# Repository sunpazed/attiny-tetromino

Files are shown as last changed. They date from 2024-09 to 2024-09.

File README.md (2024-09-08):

# attiny-tetromino 



This is my second-ever PCB, an Arduino Tetris game based around a attiny85. Most of the code was inspired by this hack https://github.com/jfoucher/attiny-tetris/ — however I made a number of modern modifications to Tetris (7-bag randomiser, DAS, debounce, NES speed improvements, new level and line system, new fonts). 

I started with a breadboard and then thought I'd try my hand at designing a PCB in Kicad. Here's [version 1](https://www.reddit.com/r/arduino/comments/1eph7te/my_first_pcb_an_arduino_attiny85_handheld/) and this project is version 2. Please excuse my poor hand soldering, as I'm only just beginning!

The game is quite small, at 50x44mm it's easily pocketable. The side profile is only 14mm, and could be make thinner by using a smaller battery holder.



## How to build your own

### Part list

The parts are relatively inexpensive, with the entire BOM and board costing less than $10 in total. To accomodate easier soldering I've selected larger surface mount components where possible, and the pads on the board are also wider.

- 1x attiny85-20su
- 1x SDD1306 monochrome OLED (128x32 pixels)
- 1x Mini 7-pin SMD toggle slide switch, [SPDT MSK-12C02](https://www.ckswitches.com/media/1424/pcm.pdf) 
- 4x SMD micro-switch 6x6x5mm
- 1x 470k SMD resistor (2512 size)
- 1x battery holder CR2032, [Keystone 1060](https://www.ckswitches.com/media/1424/pcm.pdf)

### Make the PCB

Order a PCB using the gerber files within the `pcb/fabrication` folder — simply zip this up and process the files through your favourite prototyping fab. The source also includes the Kicad project if you'd like to modify the PCB, components, or even just the silkscreen graphics.

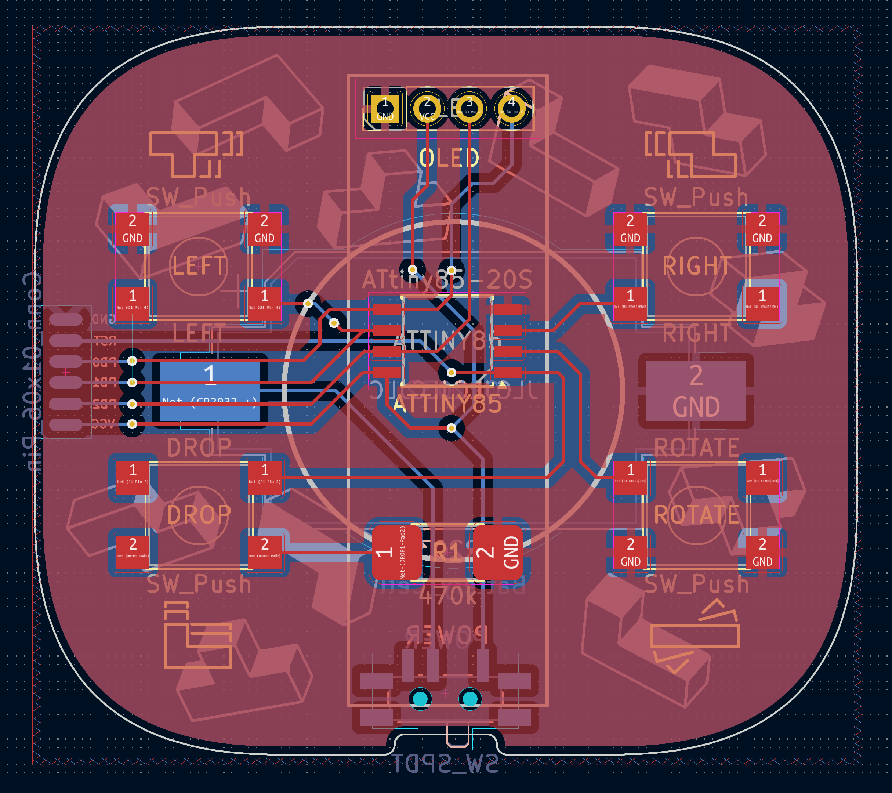
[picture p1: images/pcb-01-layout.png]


### Programming the board

The board includes 6 programming pads directly connected to the attiny. You can see them here on the right-hand side of the rear of the pcb; 

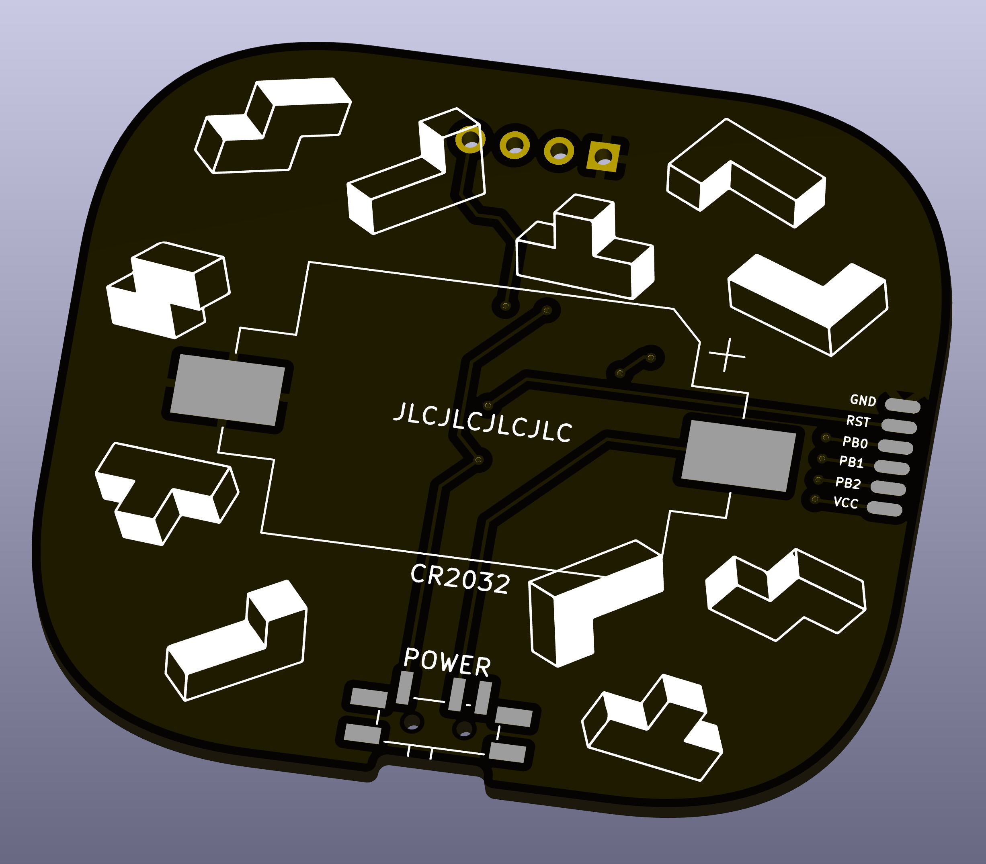
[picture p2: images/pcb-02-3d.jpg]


These can be easily connected using a SOP16 programming clip for SOIC16 chips. Only the top section of the clip is used, and is mapped to GND, RST, PB0, PB1, PB3, and VCC. Connect the programming clip to your programming device or Arduino using DuPont jumper wires — learn more at [SOICBite](https://github.com/SimonMerrett/SOICbite)

Once the board is connected, load up the Arduino IDE and test the connection by burning the bootloader to the attiny. The bootloader configuration is defined within the `attiny_tetromino.ino` project.

If the bootloader completes without issue, you can now compile and upload the `attiny_tetromino.ino` project to your board. Pop in a CR2032 battery and enjoy playing!

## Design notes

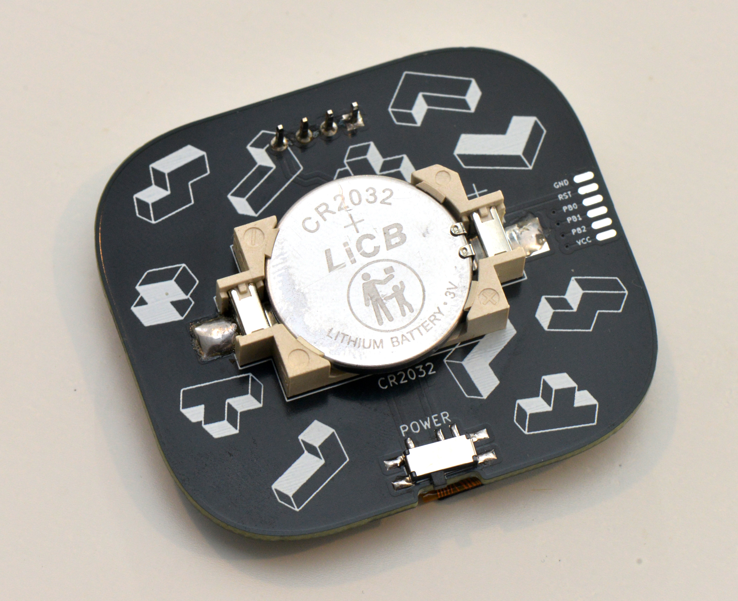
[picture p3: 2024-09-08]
images/device-rear.jpg

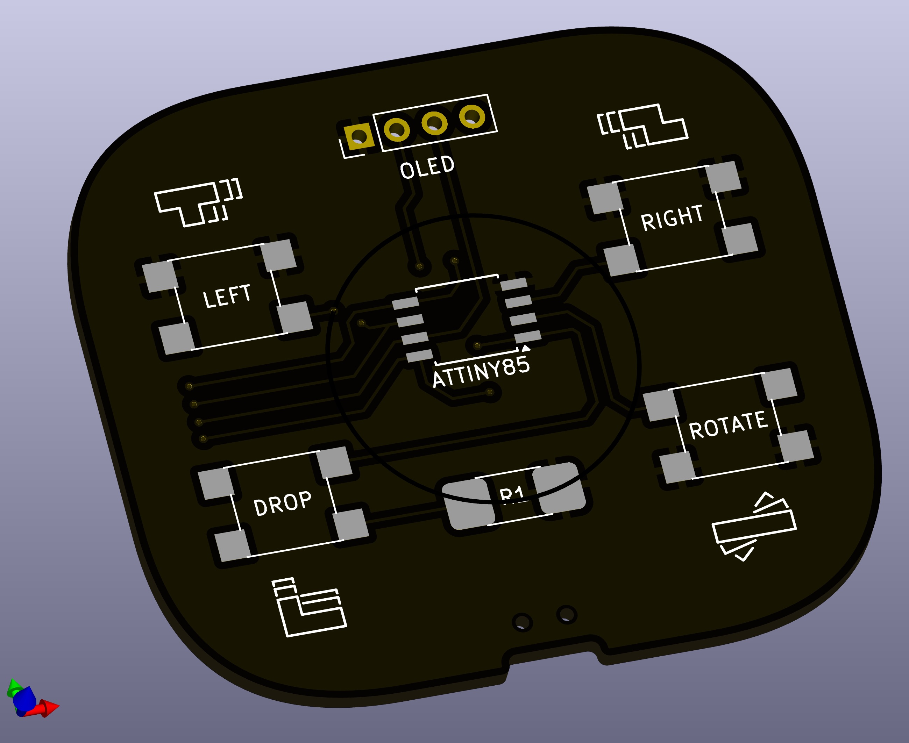
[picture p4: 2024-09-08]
images/pcb-03-3d.jpg

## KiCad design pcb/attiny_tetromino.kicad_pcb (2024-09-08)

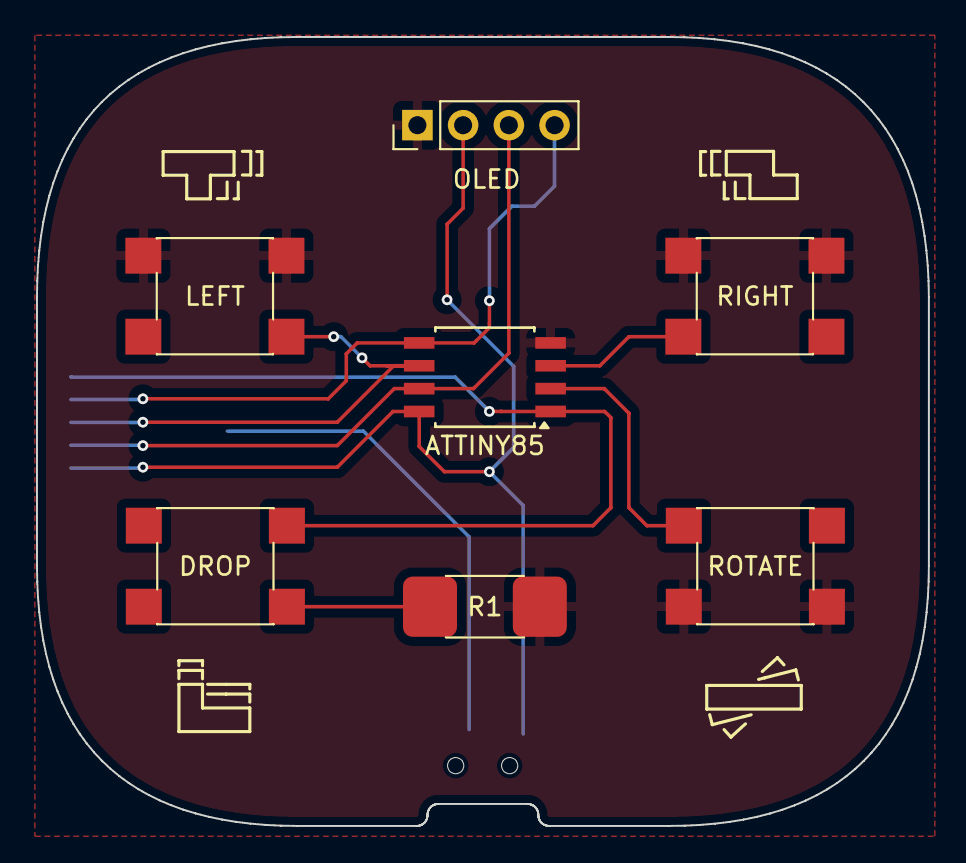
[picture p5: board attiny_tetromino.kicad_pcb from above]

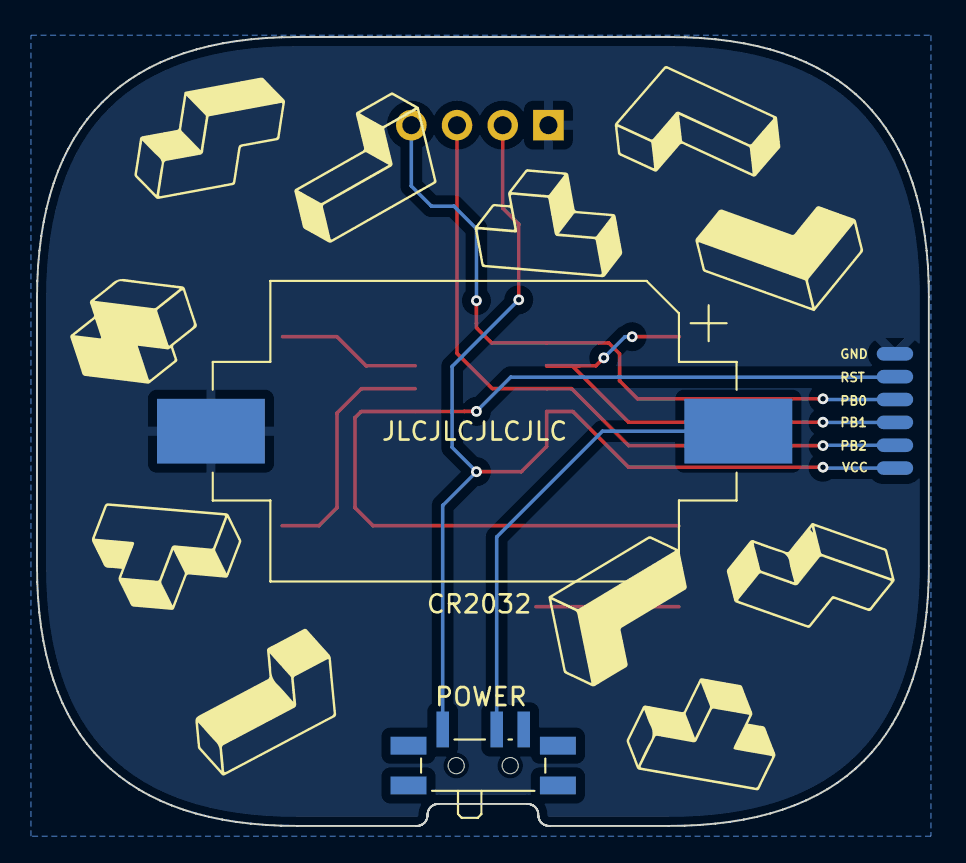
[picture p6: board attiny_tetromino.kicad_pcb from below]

Board: 2 copper layers, 49.5 x 43.8 mm, 10 parts (3 on the bottom side), 10 nets.

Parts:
ATTINY85: ATtiny85-20S; SOIC-8W_5.3x5.3mm_P1.27mm
CR2032: Battery_Cell; BatteryHolder_Keystone_1060_1x2032
DROP: SW_Push; SW_Push_1P1T_NO_6x6mm_H9.5mm
J1: Conn_01x06_Pin; SOICBite_16
LEFT: SW_Push; SW_Push_1P1T_NO_6x6mm_H9.5mm
OLED: Conn_01x04_Pin; PinHeader_1x04_P2.54mm_Vertical
POWER: SW_SPDT; SW_SPDT_PCM12
R1: 470k; R_2512_6332Metric_Pad1.40x3.35mm_HandSolder
RIGHT: SW_Push; SW_Push_1P1T_NO_6x6mm_H9.5mm
ROTATE: SW_Push; SW_Push_1P1T_NO_6x6mm_H9.5mm

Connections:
GND: ATTINY85.4 (GND), CR2032.2 (-), J1.1, LEFT.2, OLED.1, R1.2, RIGHT.2, ROTATE.2
unnamed: CR2032.1 (+), POWER.2 (B)
unnamed: DROP.2, R1.1
unnamed: ATTINY85.1 (~RESET/PB5), DROP.1, J1.2
unnamed: ATTINY85.5 (AREF/PB0), J1.3, OLED.4
unnamed: ATTINY85.6 (PB1), J1.4, LEFT.1
unnamed: ATTINY85.7 (PB2), J1.5, OLED.3
unnamed: ATTINY85.2 (XTAL1/PB3), ROTATE.1
unnamed: ATTINY85.3 (XTAL2/PB4), RIGHT.1
VCC: ATTINY85.8 (VCC), J1.6, OLED.2, POWER.1 (A)

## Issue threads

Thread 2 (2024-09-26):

Links in part list

BurningButter, 2024-09-26:
Not sure if this is intentional, so apologize if it is.
The link next to the 7-pin switch (labeled SPDT MSK-12C02) links to the same place as the one next to the battery holder (labeled Keystone 1060).
They both link to a specification sheet for the switch that you used.

BurningButter, 2024-09-26:
This is present on this Github page and on the Hackaday project page

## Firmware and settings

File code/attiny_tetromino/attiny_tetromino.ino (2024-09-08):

// attiny_tetromino - a tiny falling-block puzzle game

// 2024
// Changes made by sunpazed (https://github.com/sunpazed/attiny-tetromino)
// - Random selector changed to 7-bag randomiser to balance randomness of tetrominos
// - Tweaked speed timing for levels to match NES
// - Included "number of lines completed"  
// - Included "levels"
// - Press rotate + drop to restart game
// - Used tiny-i2c for performance 
//
// pins of attiny85 w/ basic schematic
//
//  R470k + DROP BTN    RST  -|o     |-  Vcc                CR2023 (3v)
//  ROTATE BTN          PB3  -|      |-  PB2 (SCK/SCL)      OLED SCL
//  LEFT BTN            PB4  -|      |-  PB1 (MISO)         RIGHT BUTTON 
//                      GND  -|______|-  PB0 (MOSI/SDA)     OLED SDA
// 
// Bootloader configuration;
// - B.O.D. Disabled
// - Chip; ATtiny85
// - Clock; 8 MHz (internal)
// - LTO Enabled
// - millis() / micros() Enabled
// - Timer 1 CPU

// 2022
// Changes made by Ampersand:
// - Left/Right button pins swapped
// - Scoring bug fixed (initial high score will be 0 instead of 2550)
// - High score is written to EEPROM when the game ends instead of when a line is scored

// 2021
// Original code by Jonathan Foucher
// https://github.com/jfoucher/attiny-tetris

// Choose your I2C implementation before including Tiny4kOLED.h
// The default is selected is Wire.h
#include <avr/sleep.h>
#include <EEPROM.h>

// To use the Wire library:f
// #include <Wire.h>

// To use the Adafruit's TinyWireM library:
// #include <TinyWireM.h>

// To use the TinyI2C library from https://github.com/technoblogy/tiny-i2c
#include <TinyI2CMaster.h>

// The blue OLED screen requires a long initialization on power on.
// The code to wait for it to be ready uses 20 bytes of program storage space
// If you are using a white OLED, this can be reclaimed by uncommenting
// the following line (before including Tiny4kOLED.h):
#define TINY4KOLED_QUICK_BEGIN,

#include <Tiny4kOLED.h>

#define SCREEN_WIDTH 16
#define SCREEN_HEIGHT 24

#define EEPROM_ADDR 4

#define PIN_LEFT PB4
#define PIN_RIGHT PB1
#define PIN_ROTATE PB3

#define LEVEL_DELAY 28


#define TETROMINOES_BAG_SIZE 7

uint8_t bag[TETROMINOES_BAG_SIZE];
uint8_t bagIndex = 0;

const uint8_t bitmap_lines[] PROGMEM = {
  0b01001000,0b10100000,0b01000101,0b00101110,
  0b01001000,0b10100000,0b01000101,0b10101000,
  0b01000101,0b00100000,0b01000101,0b01101100,
  0b01000101,0b00100000,0b01000101,0b00101000,
  0b01110010,0b00111000,0b01110101,0b00101110,
};

const uint8_t bitmap_score[] PROGMEM = {
  0b00000011,0b00011000,0b11001110,0b01110000,
  0b00000100,0b00100101,0b00101001,0b01000000,
  0b00000011,0b00100001,0b00101001,0b01100000,
  0b00000000,0b10100101,0b00101110,0b01000000,
  0b00000111,0b00011000,0b11001001,0b01110000,
};

bool gameRunning = false;

const uint8_t numz[] PROGMEM = {
  0b00000000,
  0b00001100, // 0
  0b00010010,
  0b00010010,
  0b00010010,
  0b00001100,

  0b00000000,
  0b00000100, // 1
  0b00001100,
  0b00000100,
  0b00000100,
  0b00000100,

  0b00000000,
  0b00011100, // 2
  0b00000010,
  0b00001100,
  0b00010000,
  0b00011110,

  0b00000000,
  0b00011100, // 3
  0b00000010,
  0b00001100,
  0b00000010,
  0b00011100,

  0b00000000,
  0b00001010, // 4
  0b00010010,
  0b00011110,
  0b00000010,
  0b00000010,

  0b00000000,
  0b00011110, // 5
  0b00010000,
  0b00011100,
  0b00000010,
  0b00011100,

  0b00000000,
  0b00001100, // 6
  0b00010000,
  0b00011100,
  0b00010010,
  0b00001100,

  0b00000000,
  0b00011110, // 7
  0b00000010,
  0b00000100,
  0b00001000,
  0b00001000,

  0b00000000,
  0b00001100, // 8
  0b00010010,
  0b00001100,
  0b00010010,
  0b00001100,

  0b00000000,
  0b00001100, // 9
  0b00010010,
  0b00001110,
  0b00000010,
  0b00001100,
};

// number shifts
const uint8_t shifts[] PROGMEM = {
        0,3,1,4,
        5,2,4,1
};


const uint8_t nums[80] PROGMEM = {
0x0,0xe,0x11,0x19,0x15,0x13,0x11,0xe,
0x0,0xe,0x4,0x4,0x4,0x4,0xc,0x4,
0x0,0x1f,0x8,0x4,0x2,0x1,0x11,0xe,
0x0,0xe,0x11,0x1,0x2,0x4,0x2,0x1f,
0x0,0x2,0x2,0x1f,0x12,0xa,0x6,0x2,
0x0,0xe,0x11,0x1,0x1,0x1e,0x10,0x1f,
0x0,0xe,0x11,0x11,0x1e,0x10,0x8,0x6,
0x0,0x8,0x8,0x8,0x4,0x2,0x1,0x1f,
0x0,0xe,0x11,0x11,0xe,0x11,0x11,0xe,
0x0,0xc,0x2,0x1,0xf,0x11,0x11,0xe,
};

const uint8_t pieces[7][16] PROGMEM = {{
0,0,1,0,
0,0,1,0,
0,0,1,0,
0,0,1,0
},{
0,0,0,0,
0,1,1,0,
0,1,1,0,
0,0,0,0
},{
0,0,0,0,
0,1,1,0,
0,0,1,1,
0,0,0,0
},{
0,0,0,0,
0,1,1,0,
1,1,0,0,
0,0,0,0
},{
0,0,0,0,
1,1,1,0,
0,1,0,0,
0,0,0,0
},{
0,1,0,0,
0,1,0,0,
1,1,0,0,
0,0,0,0
},{
0,1,0,0,
0,1,0,0,
0,1,1,0,
0,0,0,0
}};
typedef struct activePiece activePiece;
struct activePiece
{
    int x;
    uint8_t y;
    uint8_t *piece;
    uint8_t id;
};

uint8_t nextPiece[16];

uint8_t left = 20;
uint8_t n = 1;
int level = 0;
int linesCleared = 0;
uint8_t npiece; // next piece

uint8_t pixels[SCREEN_WIDTH * SCREEN_HEIGHT / 8];

bool madeLine = false;



activePiece active = { 4, 0, 0, 1 };

unsigned long elapsed = 0;
unsigned long ms = 0;
unsigned int await = 720;

unsigned long score = 0;
unsigned long highScore = 0;

void readPiece(uint8_t p[16], uint8_t n) {
  for(int i=0;i<16;i++){
    p[i] = pgm_read_byte(&pieces[n][i]);
  }
}



void setup() {

  randomSeed(analogRead(A3));
  oled.begin();
  elapsed = millis();
  ms = millis();
  oled.setInverse(false);
  for (int y = 0; y < SCREEN_HEIGHT; y++) {
    for (int x = 0; x < SCREEN_WIDTH; x++) {
      int pos = y * SCREEN_WIDTH + x;
      if (x == 0 || x >= 11 || y == SCREEN_HEIGHT - 1) {
        pixels[pos / 8] |= 1 << (pos % 8);
      }
    }
  }
//
//  EEPROM.update(EEPROM_ADDR, 0);
//  EEPROM.update(EEPROM_ADDR+8, 0);
//  EEPROM.update(EEPROM_ADDR+2, 0);

  // Read old high score

  unsigned long btm = EEPROM.read(EEPROM_ADDR);
  unsigned long top = EEPROM.read(EEPROM_ADDR+8);
  if (top == 255) {
    top = 0;
    btm = 0;
  }

  highScore = 10UL * (btm + (top << 8));
  //highScore = top;

//  if (highScore == 0xffffffff) {
//    //eeprom has not been written yet
//    highScore = 0;
//  }
  
  // Two rotations are supported, 
  // The begin() method sets the rotation to 1.
  //oled.setRotation(0);
  //oled.setFont(FONT6X8);

  pinMode(PIN_LEFT, INPUT_PULLUP);
  pinMode(PIN_RIGHT, INPUT_PULLUP);
  pinMode(PIN_ROTATE, INPUT_PULLUP);

  // setup tetromino 7-bag
  initBag();
  shuffleBag();

  uint8_t p[16];
  // npiece = random(8);
  // if (npiece == 7) {
  //   npiece = random(7);
  // }

  npiece = drawFromBag();

  readPiece(p, npiece);
  active.id = npiece;
  active.piece = p;

  // npiece = random(8);
  // if (npiece == 7) {
  //   npiece = random(7);
  // }
  npiece = drawFromBag();

  readPiece(nextPiece, npiece);
  
  // To clear all the memory, clear both rendering frames:
  oled.clear();
  drawNextPiece();
  writeHighScore();
  oled.switchRenderFrame();
  oled.clear();
  drawNextPiece();
  writeHighScore();

  //read next piece
  readPiece(nextPiece, npiece);

  // 16 pixels wide, each pixel is represented by one bit.
  // higher order bit is on the left, low order bit on the right

  draw();
  oled.switchDisplayFrame();

  oled.on();

  gameRunning = true;

}

uint8_t page_pixels[SCREEN_HEIGHT][4] = {{0, 0, 0, 0}};

void draw() {
  //oled.clear();
  uint8_t page = 0;
  
  for (uint8_t y = 0; y < SCREEN_HEIGHT; y++) {
    if (y == SCREEN_HEIGHT - 1) {
      for (uint8_t p = 0; p < 4; p++) {
        page_pixels[y][p] = 0xff;
      }
      continue;
    }
    for (uint8_t p = 0; p < 4; p++) {
      page_pixels[y][p] = 0;
    }

    page_pixels[y][0] = 1;
    page_pixels[y][3] = 0x80;
    
    for (uint8_t x = 1; x < 11; x++) {
      int pos = y * SCREEN_WIDTH + x;
      bool piecePixel = false;
      bool hasPiece = x >= active.x && y >= active.y && x < active.x + 4 && y < active.y + 4;
      if (hasPiece) {
        int ind = (y - active.y) * 4 + (x - active.x);
        piecePixel = active.piece[ind] & 1;
      }
      if (((pixels[pos / 8] >> (pos % 8)) & 1) || piecePixel) {
        uint8_t pix = x * 3 - 2;

        for (uint8_t k = 0; k < 3; k++) {
          uint8_t p = (pix + k) / 8;
          page_pixels[y][p] |= (1 << ((pix + k) % 8));
        }
      }
    }

  }
  for (uint8_t p = 0; p < 4; p++) {
    oled.setCursor(30, p);
    oled.startData();

    oled.sendData(0xff);

    for (uint8_t y = 0; y < SCREEN_HEIGHT; y++) {
      oled.repeatData(page_pixels[y][p], 3);
    }

    oled.endData();
  }
}



void writeHighScore() {
    unsigned long divisor = 1;
    for (uint8_t l = 0; l < 4; l++) {
        oled.setCursor(SCREEN_HEIGHT * 3 + 49, l);
        oled.startData();
                
        uint8_t n = (highScore / divisor) % 10;
        divisor *= 10;

        uint8_t nx = (highScore / divisor) % 10;
        if (l==1) {
          divisor *= 10;
        }

        for (uint8_t i = 1; i < 6; i++) {
          int a = pgm_read_byte(&numz[i + (n * 6)]) >> (pgm_read_byte(&shifts[l])); 
          int b = pgm_read_byte(&numz[i + (nx * 6)]) << (pgm_read_byte(&shifts[l+4])); 
          oled.sendData((byte)(a | b ) & 0xff);
        }
        oled.endData();
    }
}


void writeScore() {
    unsigned long divisor = 1;
    for (uint8_t l = 0; l < 4; l++) {
        oled.setCursor(SCREEN_HEIGHT * 3 + 41, l);
        oled.startData();
        
        uint8_t n = (score / divisor) % 10;
        divisor *= 10;

        uint8_t nx = (score / divisor) % 10;
        if (l==1) {
          divisor *= 10;
        }

        for (uint8_t i = 1; i < 6; i++) {
          int a = pgm_read_byte(&numz[i + (n * 6)]) >> (pgm_read_byte(&shifts[l])); 
          int b = pgm_read_byte(&numz[i + (nx * 6)]) << (pgm_read_byte(&shifts[l+4])); 
          oled.sendData((byte)(a | b ) & 0xff);
        }
        oled.endData();
    }

  for (uint8_t l = 0; l < 4; l++) {
      oled.setCursor(SCREEN_HEIGHT * 3 + 34, 3-l);
      oled.startData();                        
      for (uint8_t i = 0; i < 5; i++) {
        int a = pgm_read_byte(&bitmap_score[l+(i*4)]);
        oled.sendData((byte)(a));
      }
      oled.endData();
  }

}

void writeLinesCleared() {
    unsigned long divisor = 1;

    // lvl + lines
    // 00x + 999
    unsigned long level_lines = level;
    level_lines *= 10000;
    level_lines += linesCleared;

    for (uint8_t l = 0; l < 4; l++) {
        oled.setCursor(8, l);
        oled.startData();

        // int foo = analogRead(0);
                
        uint8_t n = (level_lines / divisor) % 10;
        divisor *= 10;

        uint8_t nx = (level_lines / divisor) % 10;
        if (l==1) {
          divisor *= 10;
        }

        for (uint8_t i = 1; i < 6; i++) {
          int a = pgm_read_byte(&numz[i + (n * 6)]) >> (pgm_read_byte(&shifts[l])); 
          int b = pgm_read_byte(&numz[i + (nx * 6)]) << (pgm_read_byte(&shifts[l+4])); 
          if (l==2) {
           oled.sendData((byte)(0 | b ) & 0xff);
          } else {
           oled.sendData((byte)(a | b ) & 0xff);
          }
        }
        oled.endData();
    }


  for (uint8_t l = 0; l < 4; l++) {
      oled.setCursor(1, 3-l);
      oled.startData();                        
      for (uint8_t i = 0; i < 5; i++) {
        int a = pgm_read_byte(&bitmap_lines[l+(i*4)]);
        oled.sendData((byte)(a));
      }
      oled.endData();
  }

}


void drawNextPiece() {
  for (uint8_t y = 0; y < 4; y++) {
    for (uint8_t i = 0; i < 4; i++) {
      page_pixels[y][i] = 0;
    }
    for (uint8_t x = 4; x < 8; x++) {
      bool piecePixel = false;
      int ind = y * 4 + x - 4;
      piecePixel = nextPiece[ind] & 1;
      
      
      if (piecePixel) {
        uint8_t pix = x * 3 - 2;
        for (uint8_t k = 0; k < 3; k++) {
          uint8_t p = (pix + k) / 8;
          page_pixels[y][p] |= (1 << ((pix + k) % 8));
        }
      }
    }
  }

  
  for (uint8_t p = 0; p < 4; p++) {
    // oled.setCursor(5, p);
    oled.setCursor(16, p);
    oled.startData();
    for (uint8_t y = 0; y < 4; y++) {
      oled.repeatData(page_pixels[y][p], 3);
    }

    oled.endData();
  }
}

unsigned long lastMoved = 0;
unsigned long lastRotated = 0;


bool canMoveDown() {
    for (uint8_t i = 0; i < 4;i++) {
        for (uint8_t j = 0; j < 4;j++) {
            int pos = (active.y + i + 1) * SCREEN_WIDTH + active.x + j;
            int below = (pixels[pos / 8] >> (pos % 8)) & 1;

            if (active.piece[i * 4 + j] && below) {
                return false;
            }
        }
    }
    
    return true;
}

bool canMoveLeft() {
    for (uint8_t i = 0; i < 4;i++) {
        for (uint8_t j = 0; j < 4;j++) {
            int pos = (active.y + i) * SCREEN_WIDTH + active.x + j - 1;
            uint8_t left = (pixels[pos / 8] >> (pos % 8)) & 1;

            if (active.piece[i * 4 + j] && left) {
                return false;
            }
        }
    }
    
    return true;
}
bool canMoveRight() {
    for (uint8_t i = 0; i < 4;i++) {
        for (uint8_t j = 0; j < 4;j++) {
            if (active.piece[i * 4 + j] == 1) {
              int pos = (active.y + i) * SCREEN_WIDTH + active.x + j + 1;
              uint8_t right = (pixels[pos / 8] >> (pos % 8)) & 1;
              if (active.piece[i * 4 + j] && right) {
                return false;
              }
            }
        }
    }
    
    return true;
}

void rotatePiece(uint8_t data[16], uint8_t newData[16]) {
    for(uint8_t i = 0; i < 4; i++) {
        for(uint8_t j = 0; j < 4; j++) {
          newData[j * 4 + 3 - i] = data[i * 4 + j];
        }
    }
}

void getAwait() {
  if (level == 0) {
    await = LEVEL_DELAY*17;
  } else if(level == 1) {
    await = LEVEL_DELAY*16;
  } else if(level == 2) {
    await = LEVEL_DELAY*15;
  } else if(level == 3) {
    await = LEVEL_DELAY*14;
  } else if(level == 4) {
    await = LEVEL_DELAY*13;
  } else if(level == 5) {
    await = LEVEL_DELAY*11;
  } else if(level == 6) {
    await = LEVEL_DELAY*10;
  } else if(level == 7) {
    await = LEVEL_DELAY*8;
  } else if(level == 8) {
    await = LEVEL_DELAY*7;
  } else if(level == 9) {
    await = LEVEL_DELAY*6;
  } else if(level == 10) {
    await = LEVEL_DELAY*5;
  } else if(level <= 13) {
    await = LEVEL_DELAY*4;
  } else if(level <= 16) {
    await = LEVEL_DELAY*2;
  } else if(level <= 20) {
    await = LEVEL_DELAY;
  } else if(level > 20) {
    await = LEVEL_DELAY;
  } else {
    await = LEVEL_DELAY*17;
  }
}

void(* resetFunc) (void) = 0;

void loop() {

  if (gameRunning) {

    gameLoop();

  } else {

    if ((analogRead(0) < 950) && ((PINB >> PIN_ROTATE) & 1) == 0)  {

      resetFunc();
      // for (uint8_t y = 0; y < SCREEN_HEIGHT; y++) {
      //   if (y == SCREEN_HEIGHT - 1) {
      //     for (uint8_t p = 0; p < 4; p++) {
      //       page_pixels[y][p] = 0x00;
      //     }
      //     continue;
      //   }      
      // }

      // // draw();
      // gameRunning = true;

    }

  }

}

void gameLoop() {
  if (madeLine) {
    madeLine = false;
    oled.setInverse(false);
  }
  ms = millis();
  if (lastMoved + 100 < ms) {
    bool rPressed = ((PINB >> PIN_RIGHT) & 1) == 0;
    bool lPressed = ((PINB >> PIN_LEFT) & 1) == 0;
    
    if (rPressed && canMoveRight()) {
      active.x += 1;
    }
    
    if (lPressed && canMoveLeft()) {
      active.x -= 1;
    }
    lastMoved = ms;
  }

  getAwait();

  // DROP button pressed?
  if (analogRead(0) < 950) {
  // if (analogRead(0) < 350) {
    score +=1;
    await = 8;
  }
  
  if (((PINB >> PIN_ROTATE) & 1) == 0 && lastRotated + 160 < ms) {
    uint8_t np[16];
    uint8_t op[16];
    for (uint8_t l = 0; l < 16; l++) {
      op[l] = active.piece[l];
    }

    //Rotate piece
    rotatePiece(op, np);
    // set rotated piece as active
    active.piece = np;

    int old_x = active.x;

    //check collisions
    
    bool movedLeft = false;
    bool movedRight = false;
    if(!canMoveRight()) {
      active.x -= 1;
      movedLeft = true;
    }
    if(!canMoveLeft()) {
      active.x += 1;
      movedRight = true;
    }

    if (movedLeft && movedRight) {
      // could not rotate
      active.piece = op;
      active.x = old_x;
    } else {
      if (movedLeft) {
        while(!canMoveRight()) {
          active.x -= 1;
        }
        active.x +=1;
      }
      if (movedRight) {
        while(!canMoveLeft()) {
          active.x += 1;
        }
        active.x -=1;
      }
    }
    
    lastRotated = ms;
  }
  
  if (elapsed + await < ms) {
    
    if (canMoveDown()) {
      active.y += 1;
    } else {
      // cannot move down, make piece part of pixels
      for (uint8_t i = 0; i < 4;i++) {
        for (uint8_t j = 0; j < 4;j++) {
          int pos = (active.y + i) * SCREEN_WIDTH + active.x + j;

          if (active.piece[i * 4 + j] == 1) {
            pixels[pos / 8] |= 1 << (pos % 8);
          }
        }
      }

      //check if a line was created
      uint8_t nlines = 0;
      for (uint8_t y = 0; y < SCREEN_HEIGHT - 1; y++) {
        int pos = y * SCREEN_WIDTH / 8;
        
        if (pixels[pos] == 0xFF && pixels[pos + 1] == 0xFF) {
          nlines++;
          madeLine = true;
          // move all pixels above
          
          for (uint8_t y2 = y; y2 >= 2; y2--) {
            int p = y2 * SCREEN_WIDTH / 8;
            
            pixels[p] = pixels[p - 2];
            pixels[p + 1] = pixels[p - 1];
          }
        }
      }

      if (nlines > 0) {
        linesCleared += nlines;
        if (nlines == 1) {
          score += 40 * (level + 1);
        } else if (nlines == 2) {
          score += 100 * (level + 1);
        } else if (nlines == 3) {
          score += 300 * (level + 1);
        } else if (nlines == 4) {
          score += 1200 * (level + 1);
        }
      }

      

      //Check if game over
      if (active.y <=1 ) {
         unsigned long toWrite = highScore / 10;
          EEPROM.update(EEPROM_ADDR+8, (uint8_t)((toWrite >> 8) & 0xff));
          EEPROM.update(EEPROM_ADDR, (uint8_t)(toWrite & 0xff));
          gameRunning = false;
        // oled.setInverse(true);
        // set_sleep_mode(SLEEP_MODE_PWR_DOWN); // sleep mode is set here
        // sleep_enable();      
        // sleep_mode();     
      }

      if (madeLine) {
        oled.setInverse(true);
        //save high score
        if (score > highScore) {
          highScore = score;
        }
      }
      
      active = { 4, 0, 0, npiece };
      uint8_t p[16];
      readPiece(p, npiece);
      active.piece = p;
      
      // npiece = random(8);
      // if (npiece == 7 || npiece == active.id) {
      //   npiece = random(7);
      // }
      npiece = drawFromBag();

      readPiece(nextPiece, npiece);
      
      

      drawNextPiece();
      writeHighScore();

      oled.switchRenderFrame();
      drawNextPiece();
      writeHighScore();
      oled.switchRenderFrame();
    }
    
    elapsed = ms;
    
    if (linesCleared > (level+1) * 10) {
      level += 1;
    }
  }
  oled.switchRenderFrame();
  
  draw();
  writeScore();
  writeLinesCleared();

  oled.switchDisplayFrame();

}

// init the 7-bag
void initBag() {
    for (uint8_t i = 0; i < TETROMINOES_BAG_SIZE; i++) {
        bag[i] = i;
    }
}

// shuffle the bag when empty
void shuffleBag() {
    for (uint8_t i = 0; i < TETROMINOES_BAG_SIZE; i++) {
        uint8_t j = random(TETROMINOES_BAG_SIZE);
        uint8_t temp = bag[i];
        bag[i] = bag[j];
        bag[j] = temp;
    }
    bagIndex = 0;
}

// draw a single item from the bag
uint8_t drawFromBag() {
    if (bagIndex >= TETROMINOES_BAG_SIZE) {
        shuffleBag();
    }
    return bag[bagIndex++];
}
